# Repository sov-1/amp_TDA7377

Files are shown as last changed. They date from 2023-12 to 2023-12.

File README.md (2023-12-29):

 # Amplifier with audio-car amp TDA7377

This repo contains no only desing files for this amplifier but also an easy design for a coupling board that allows use the IC in any protoboard, this is under _proto_ folder wich has the gerber and .nc files for fabrication.

---
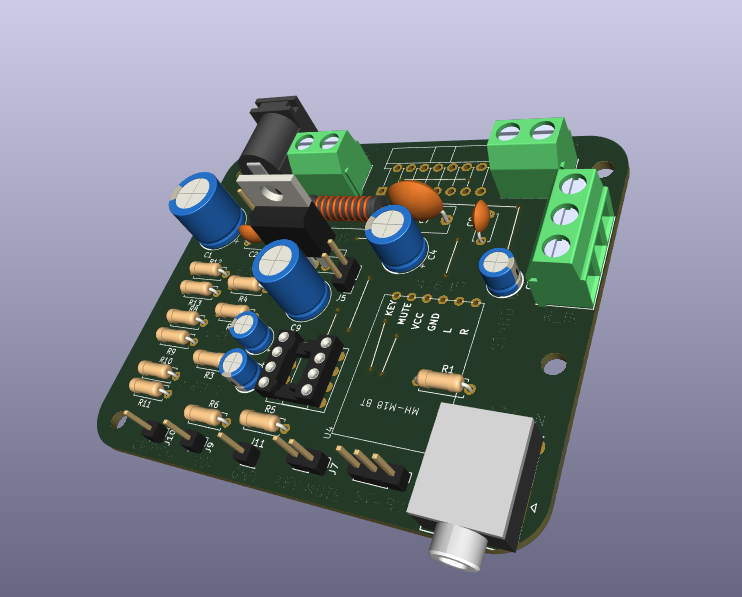
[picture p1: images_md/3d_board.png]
3D view


The goal it's to create a complete audio device 2.0 with audio jack - bluetooth input the cheapest way.
Following that, all is minded to be throug hole components, also using less space possible and carving circuits with a simple CNC 3018.

---
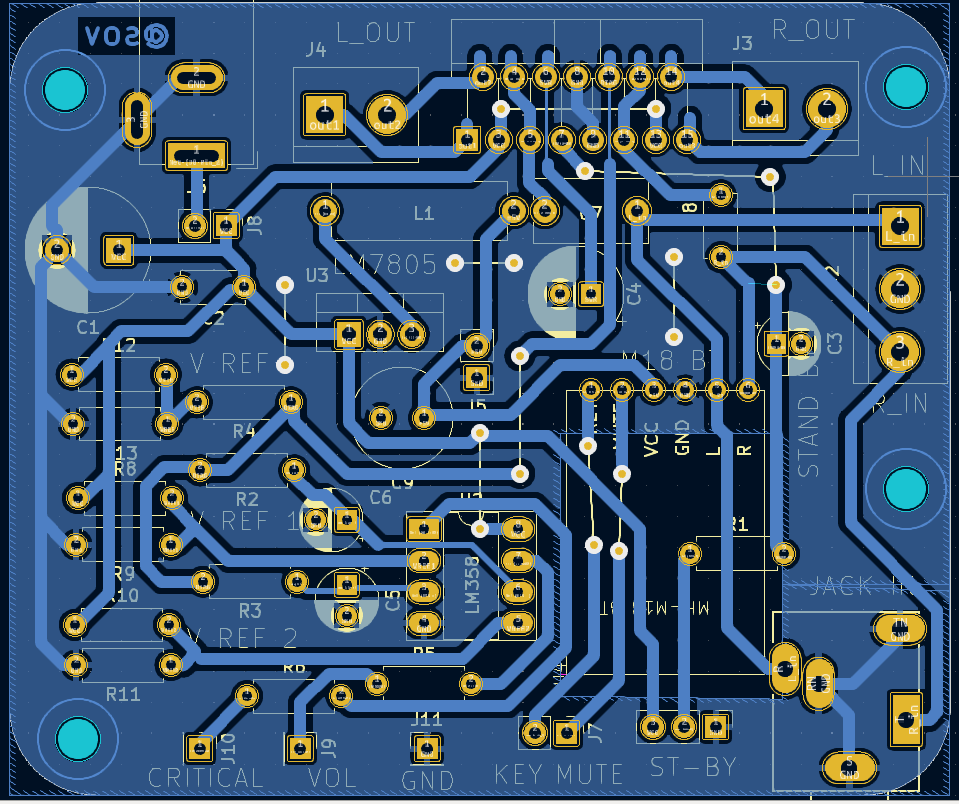
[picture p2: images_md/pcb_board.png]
pcb stage


At actual stage I got the basic functions (stereo input with audio Jack and bluetooth) but it's lacking the front board with leds and control, including switchs for power.

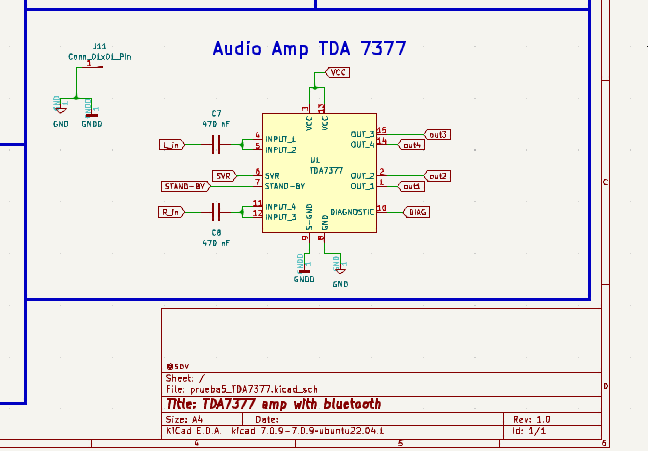
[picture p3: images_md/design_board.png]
circuit diagram


---

Some files in this project, like CAD models (.stp files) bornier and DC jack are not free and was obtained in web research.

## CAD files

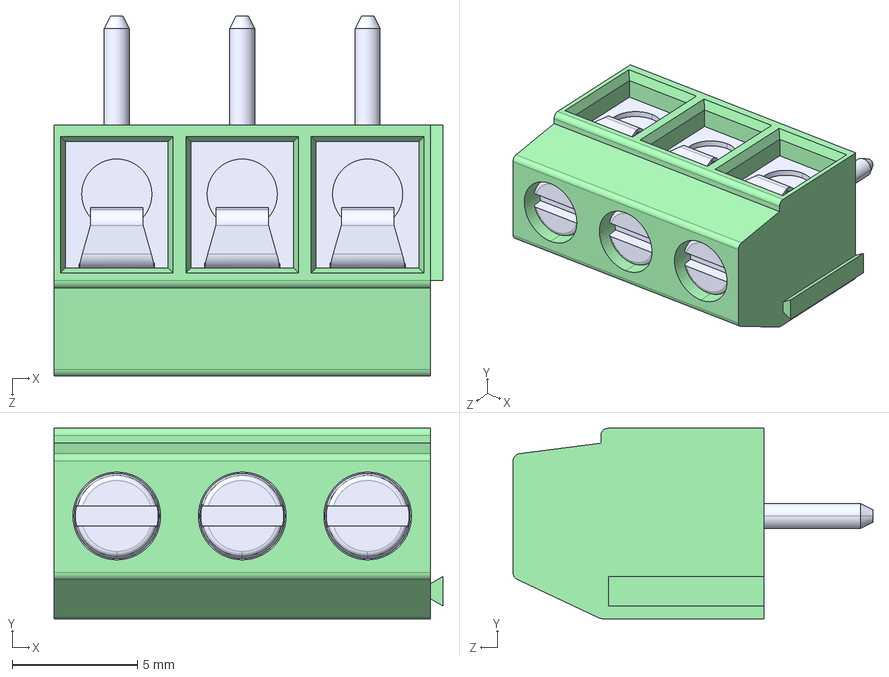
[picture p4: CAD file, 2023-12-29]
prueba5_TDA7377/terminalBlock_03.step
15.5 x 7.60 x 14.4 mm

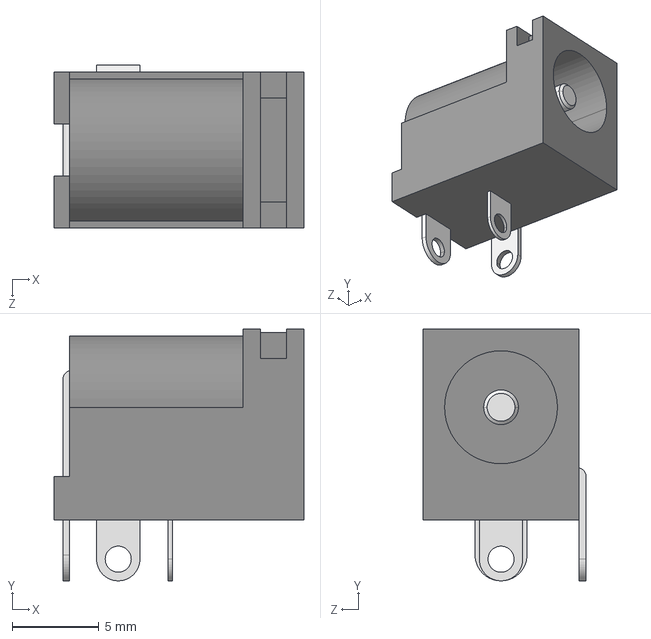
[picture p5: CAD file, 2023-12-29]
prueba5_TDA7377/JackDC_PJ-002AH.step
14.4 x 14.5 x 9.40 mm

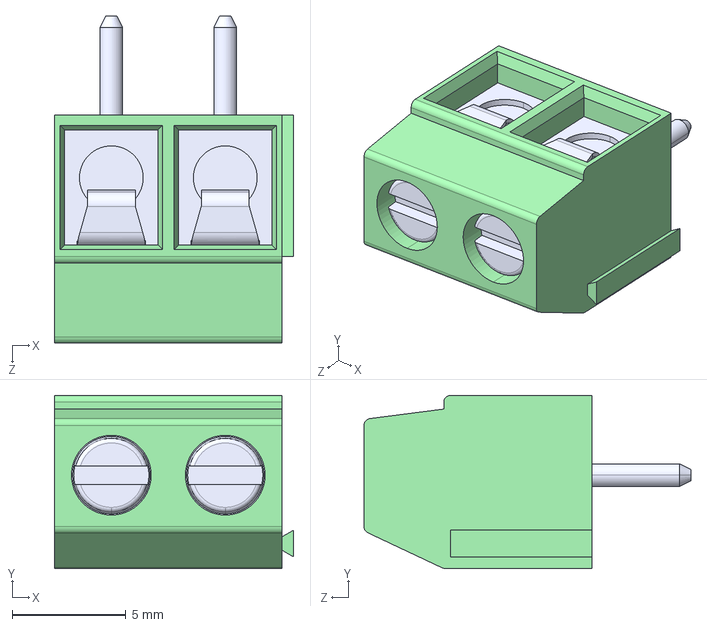
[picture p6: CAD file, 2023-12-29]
prueba5_TDA7377/terminalBlock_02.step
10.5 x 7.60 x 14.4 mm

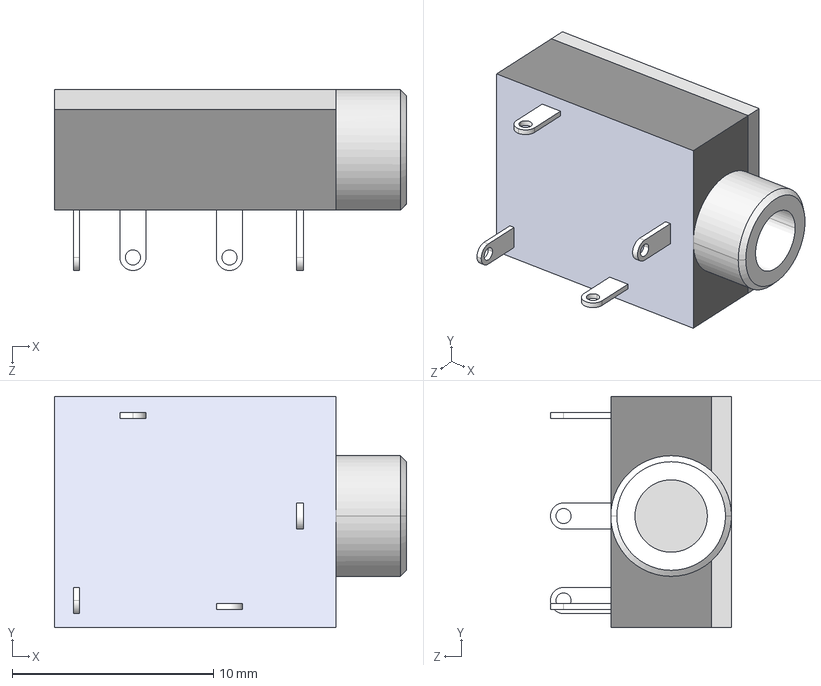
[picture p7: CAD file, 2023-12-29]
prueba5_TDA7377/AudioJack_SJ1-3514N.step
17.5 x 11.5 x 9.00 mm

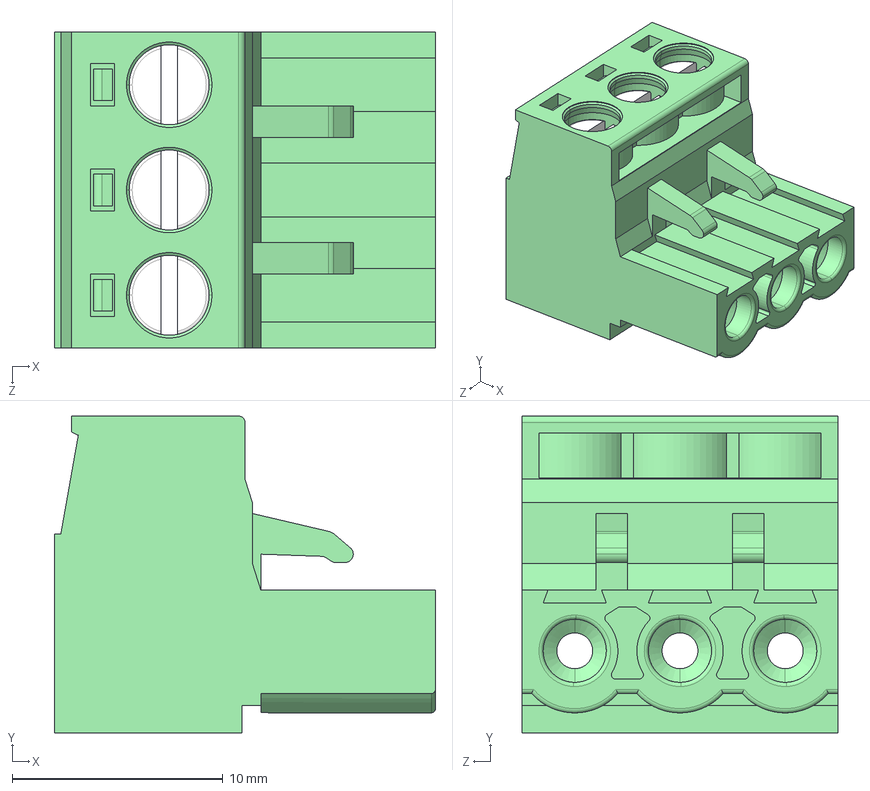
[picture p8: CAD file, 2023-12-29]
prueba5_TDA7377/terminalBlock_macho_03.step
18.1 x 15.1 x 15.0 mm

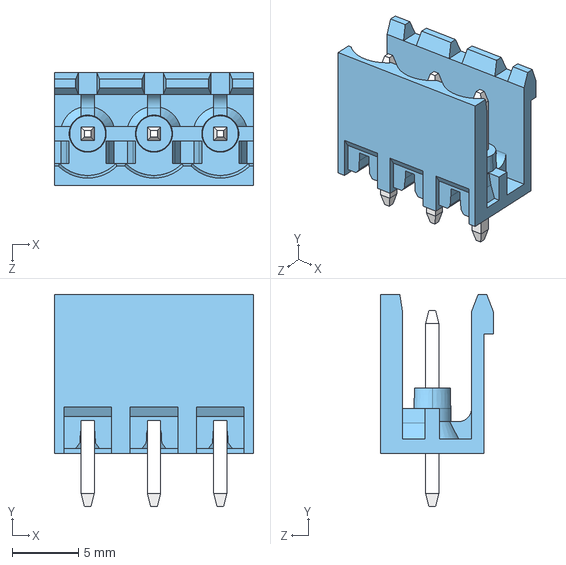
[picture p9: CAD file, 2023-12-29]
prueba5_TDA7377/terminalBlock_hembra_03.step
15.0 x 16.0 x 8.50 mm

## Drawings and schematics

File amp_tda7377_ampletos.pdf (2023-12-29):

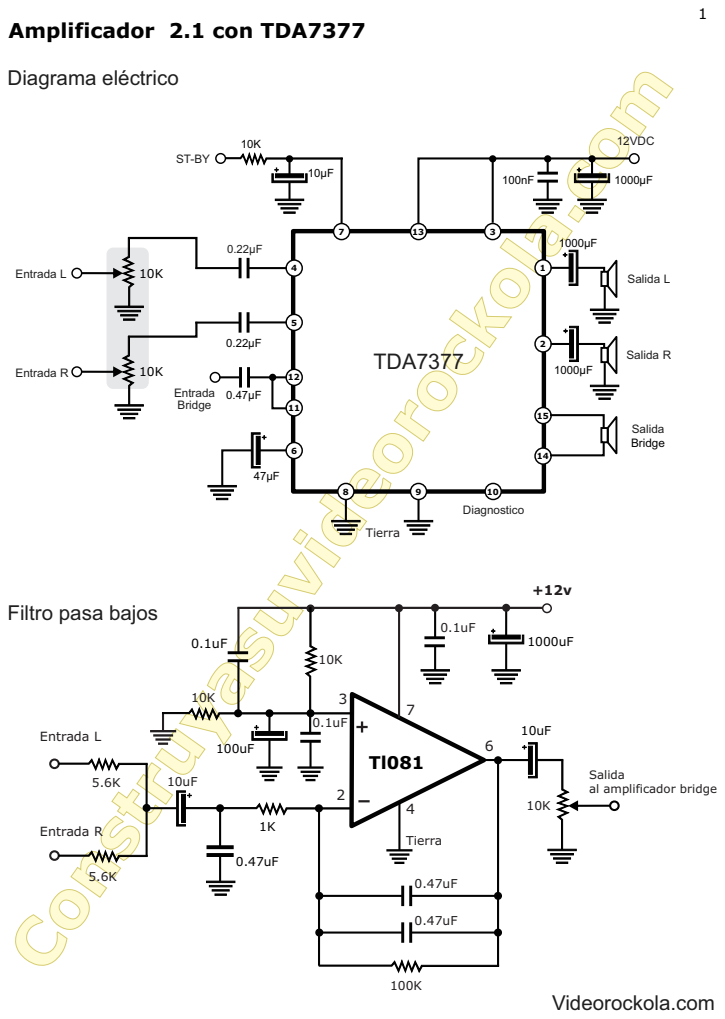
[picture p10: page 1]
Diagnostico; Entrada 0.47µF; 12VDC; Salida L; Salida Bridge; Salida R; TDA7377; Amplificador 2.1 con TDA7377; Diagrama eléctrico; Entrada L; Tierra; Entrada R; Bridge; Videorockola.com

Filtro pasa bajos

Salida
al amplificador bridge

## Preamplificador estéreo

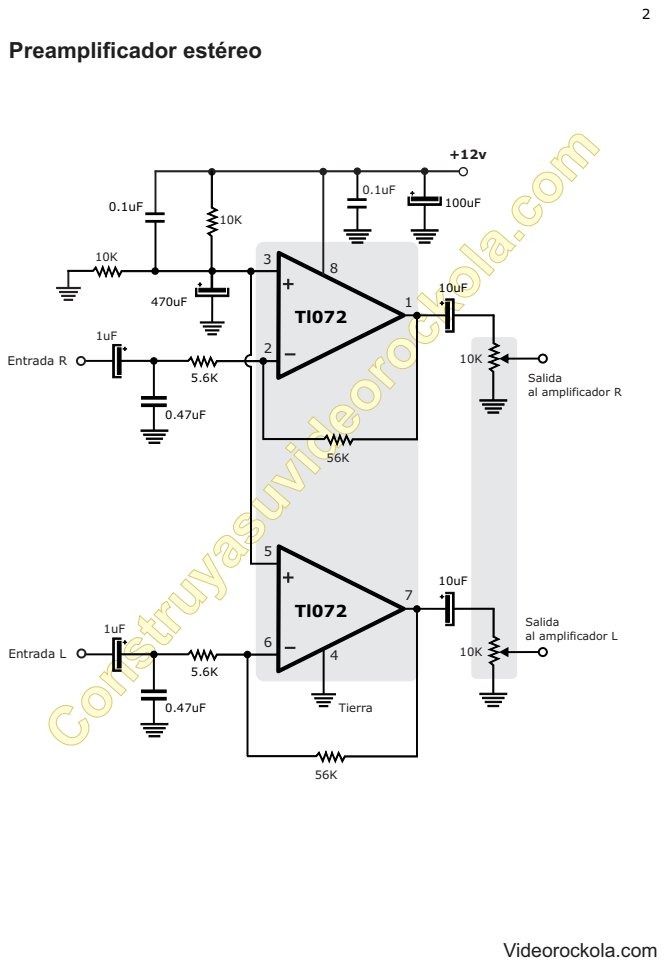
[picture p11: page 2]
Construyasuvideorockola.com; Salida al amplificador R; Entrada R; Salida al amplificador L 1uF; Tierra; Entrada L

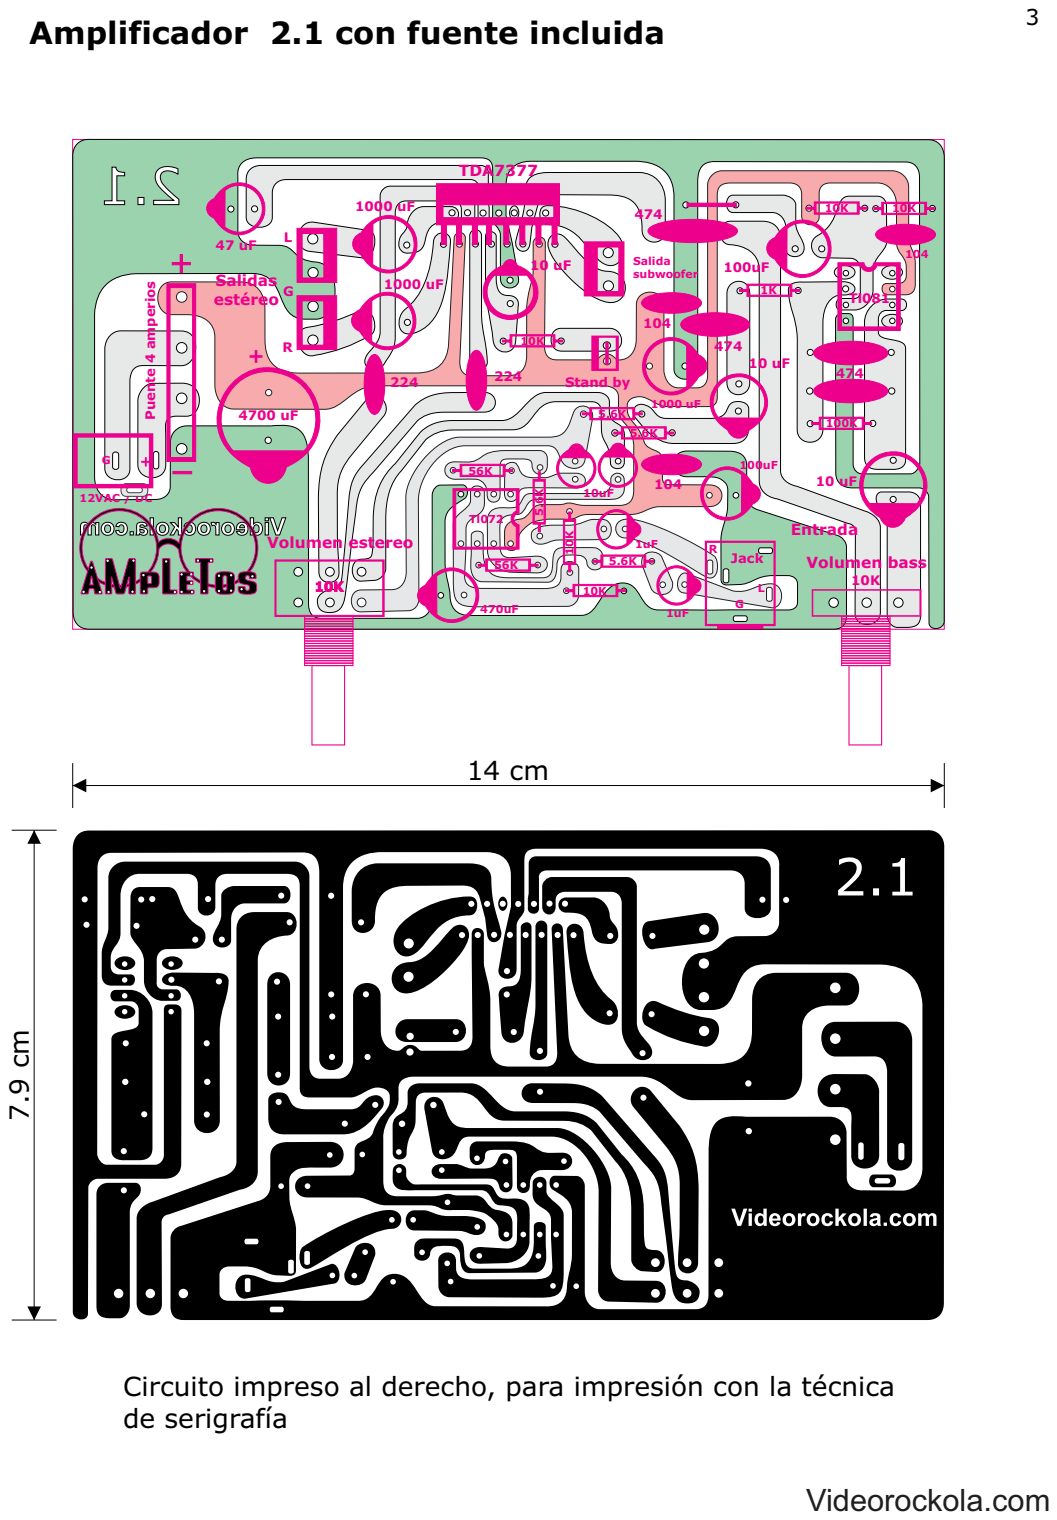
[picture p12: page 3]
5.6K ¹⁰K 5.6K; 12VAC / DC; Salida subwoofer; Stand by; Salidas estéreo; TDA7377; Volumen estereo; Volumen bass; Entrada; Jack; Puente 4 amperios

Amplificador 2.1 con fuente incluida

Circuito impreso al derecho, para impresión con la técnica
de serigrafía

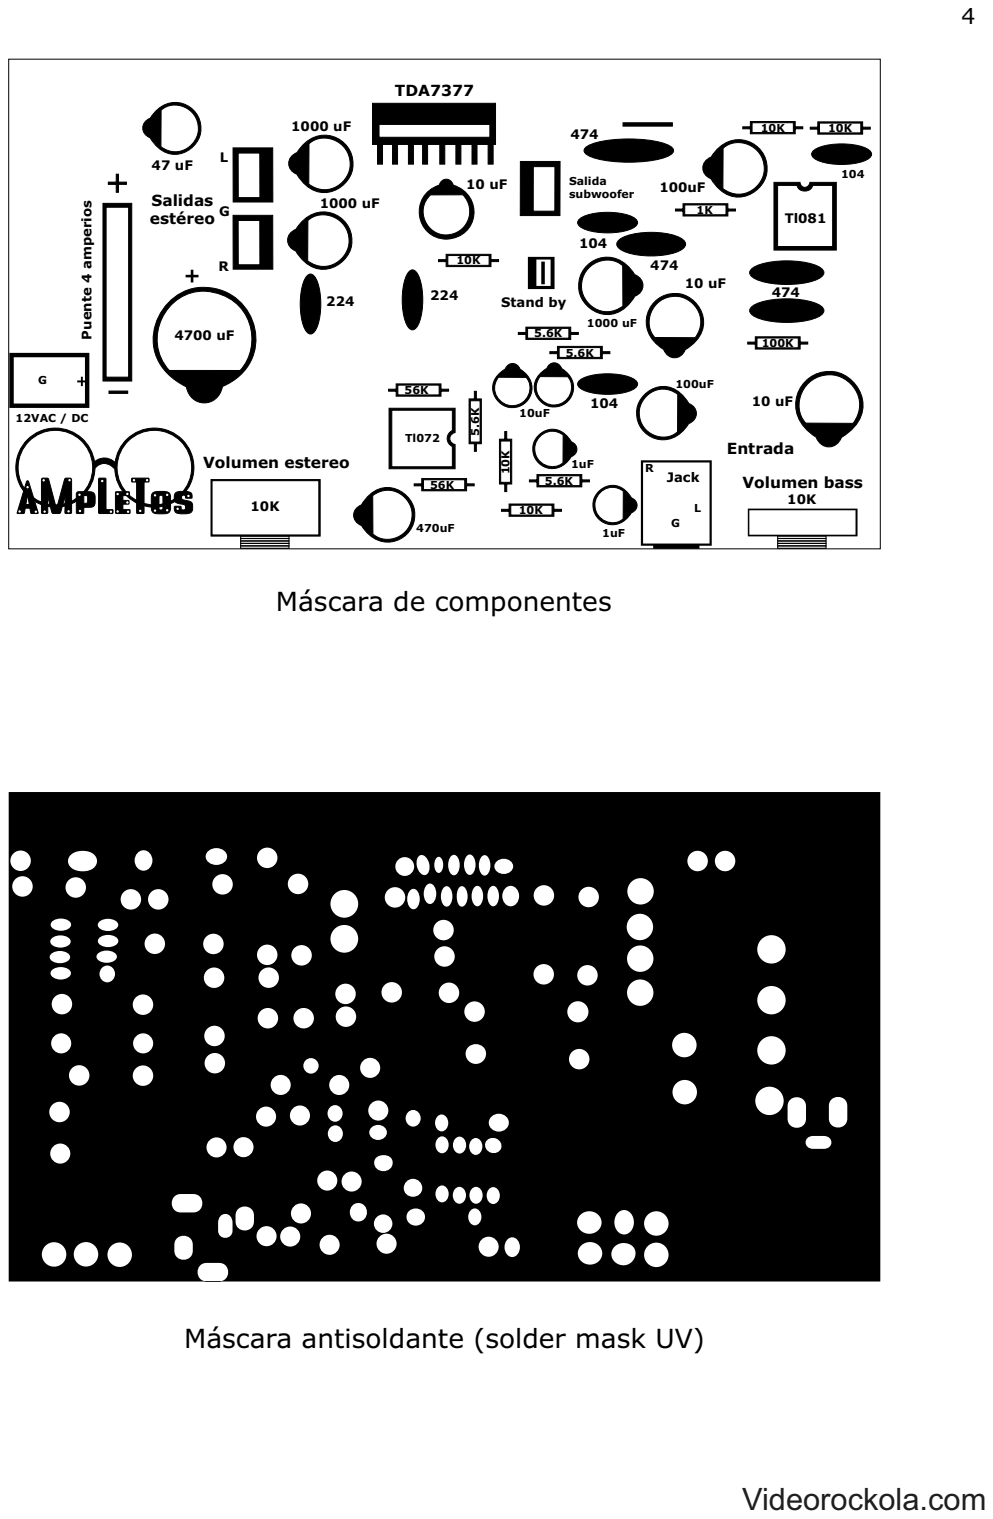
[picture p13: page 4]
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

Máscara de componentes

Máscara antisoldante (solder mask UV)

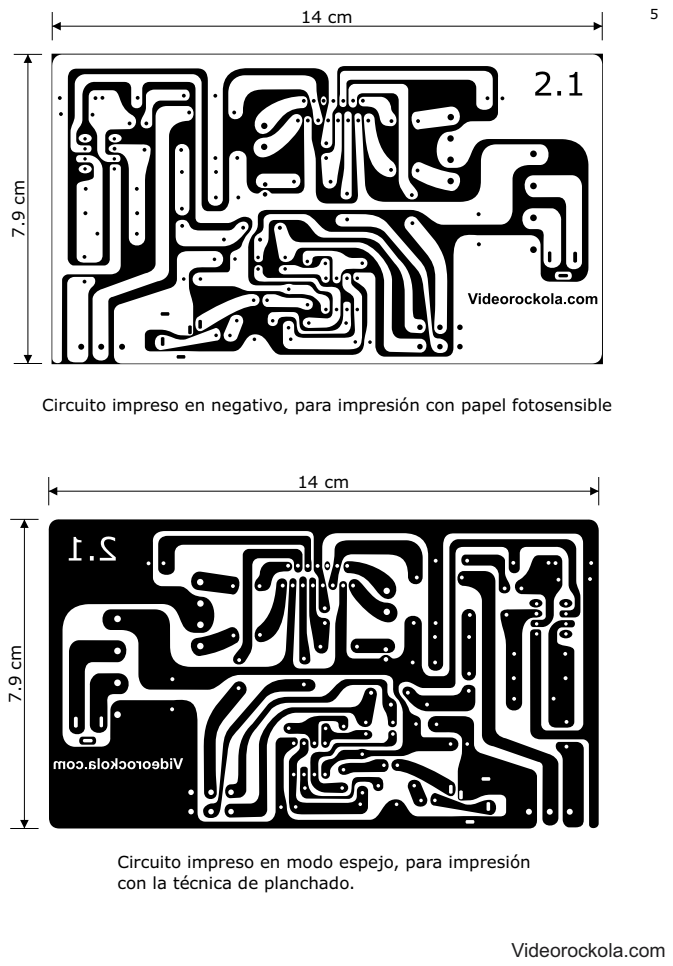
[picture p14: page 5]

Circuito impreso en negativo, para impresión con papel fotosensible

Circuito impreso en modo espejo, para impresión
con la técnica de planchado.

## Diagrama de conexión

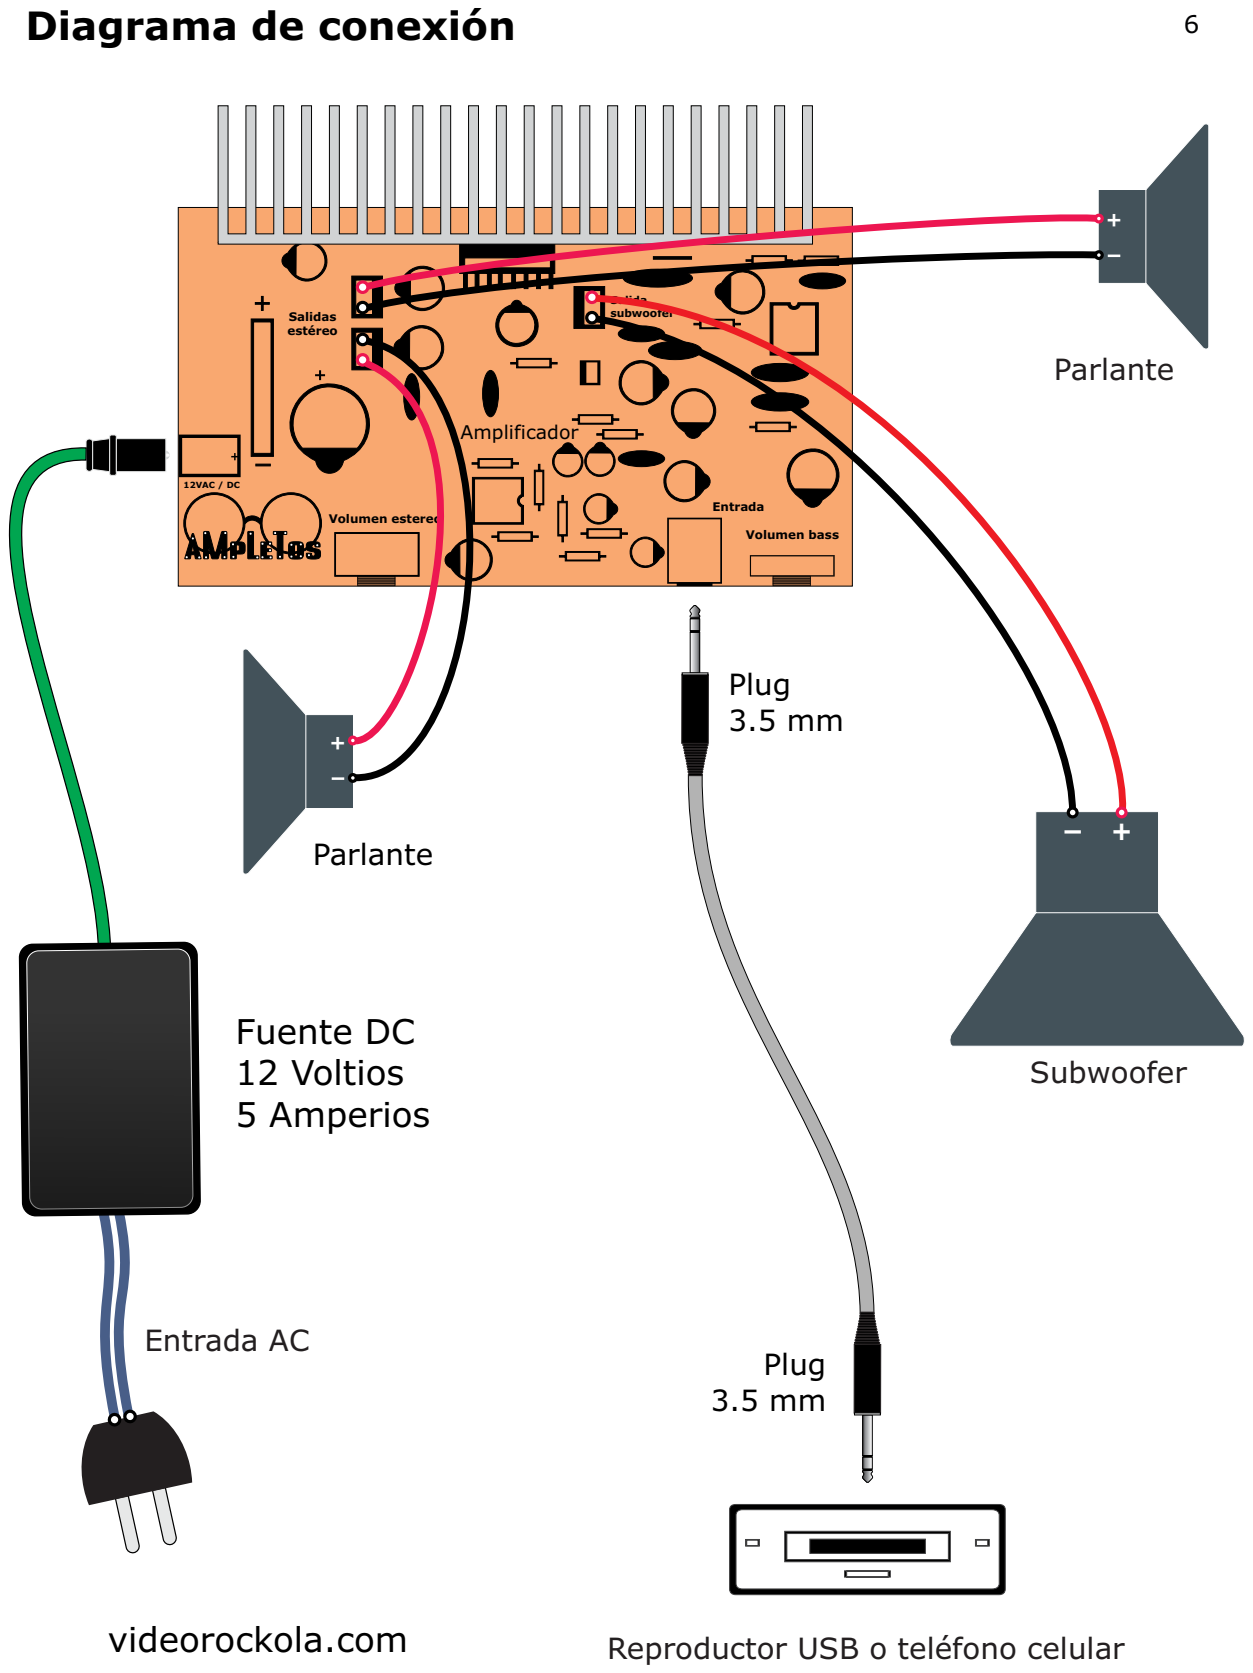
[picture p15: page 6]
12VAC / DC; Salida; Salidas; subwoofer; estéreo; Volumen estereo; Volumen bass; Entrada; Fuente DC 12 Voltios 5 Amperios; Entrada AC; Parlante; videorockola.com; Reproductor USB o teléfono celular; Amplificador; Plug 3.5 mm; Subwoofer

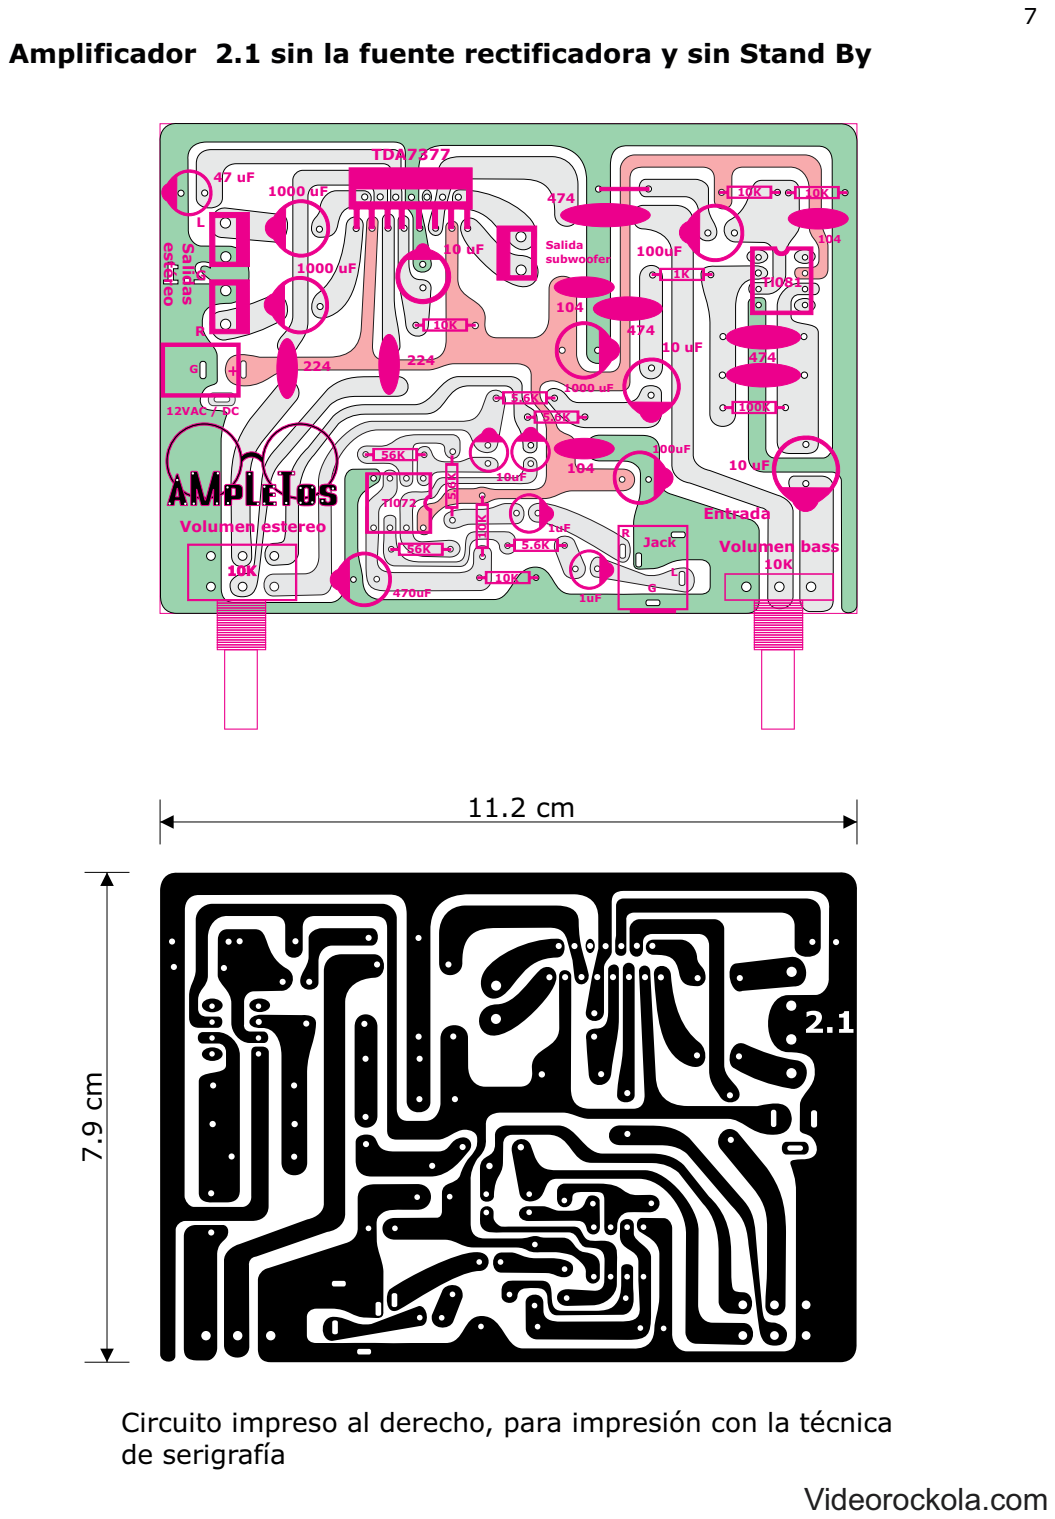
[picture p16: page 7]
5.6K ¹⁰K 5.6K; Salida subwoofer; estéreo; Salidas; TDA7377; Volumen estereo; Volumen bass; Entrada; Jack; 12VAC / DC

Amplificador 2.1 sin la fuente rectificadora y sin Stand By

Circuito impreso al derecho, para impresión con la técnica
de serigrafía

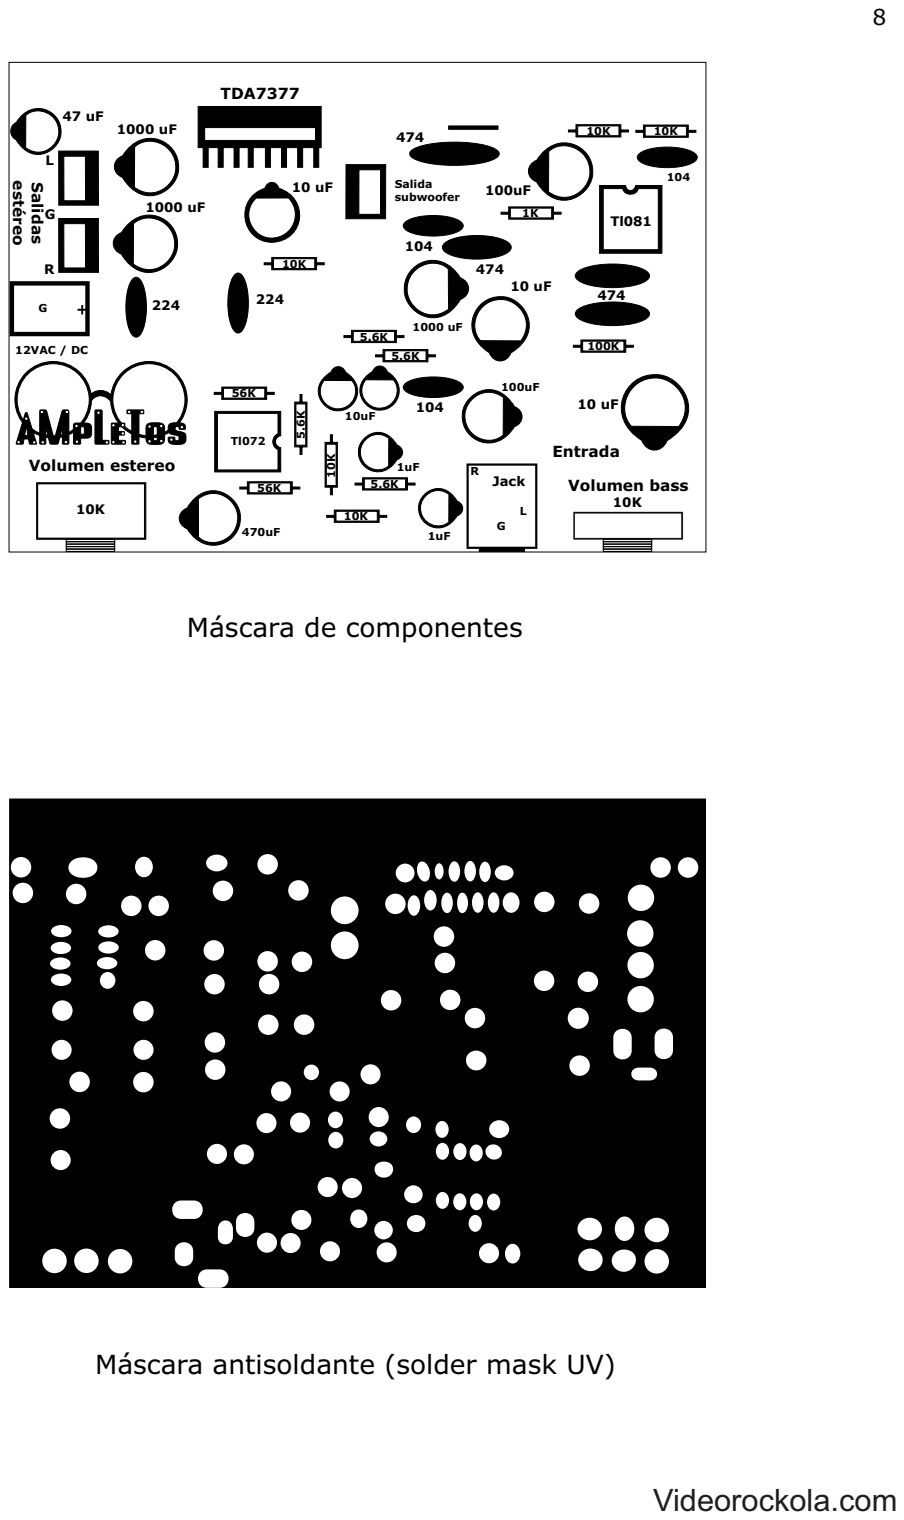
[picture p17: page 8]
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

Máscara de componentes

Máscara antisoldante (solder mask UV)

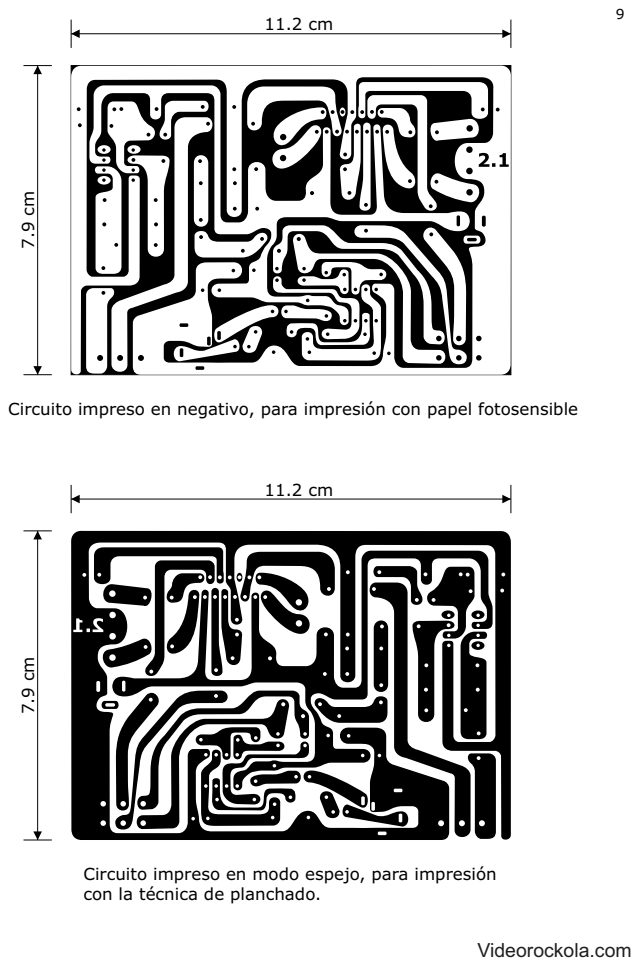
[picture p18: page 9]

Circuito impreso en negativo, para impresión con papel fotosensible

Circuito impreso en modo espejo, para impresión
con la técnica de planchado.

Lista de materiales

Circuitos integrados

1 TDA7377
1 Tl081
1 Tl072

Resistencias

2 Resistencias de 56K (verde, azul, naranja) 1 Resistencia de 100K (café, negro, amarillo) 5 Resistencias de 10K (café, negro, naranja) 1 Resistencia de 1K (café, negro, rojo)
4 Resistencias de 5.6K (verde, azul, rojo)

Condensadores

3 Condensadores de 1000uF a 16V en adelante 2 Condensadores de 100uF a 16V en adelante 5 Condensadores de 10uF a 16V en adelante 1 Condensador de 47uF a 16V en adelante
1 Condensador de 470uF a 16V en adelante 1 Condensador de 4.700uF a 16V en adelante 2 condensadores de 0.22uF (224) poliéster
4 condensadores de 0.47uF (474) poliéster
3 Condensadores de 0.1uF (104) poliéster
2 condensadores de 1uF a 16 voltios en adelante

Otros

1 potenciómetro doble de 10K
1 potenciómetro sencillo de 10K
1 conector de 2.54 mm de 2 pines (opcional)
3 conectores tipo bornera (Bloque) de 2 pines
Disipador de calor de 12 cm de largo x 5 cm de alto y 2 cm de grueso. 1 puente de diodos de 4 amperios en adelante (tipo peine)
Jack de 3.5 milímetros
Cable con plug estéreo de 3.5 milímetros en cada extremo.
Jack DC de 2.1 milímetros
2 bases para circuito integrado de 8 pines DIP
1 transformador de 12V AC y 5 amperios. (sólo en caso de hacer la versión con fuente incluida. También puede ser una fuente DC de 12VDC y 5 amperios, o una batería.

10

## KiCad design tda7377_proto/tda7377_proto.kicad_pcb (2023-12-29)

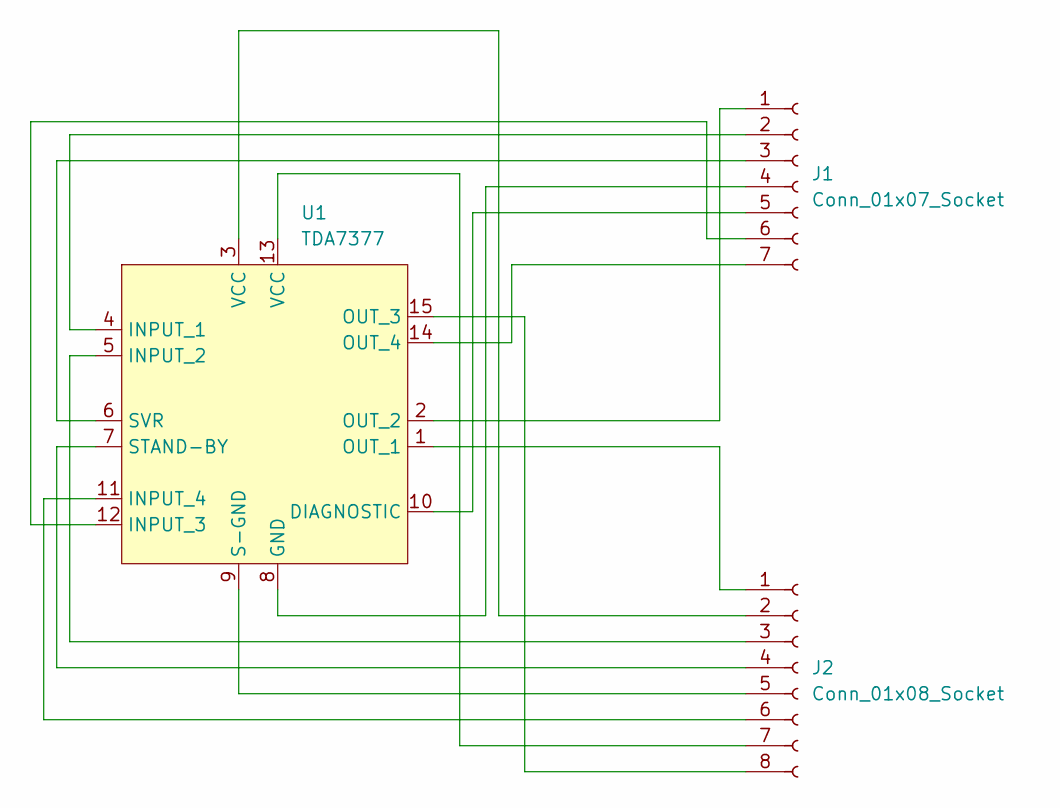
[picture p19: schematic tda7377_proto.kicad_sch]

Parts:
J1: Conn_01x07_Socket; PinHeader_1x07_P2.54mm_Vertical
J2: Conn_01x08_Socket; PinHeader_1x08_P2.54mm_Vertical
U1: TDA7377; TO-220-15_P2.54x2.54mm_StaggerOdd_Lead4.58mm_Vertical

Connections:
unnamed: J1.1, U1.2 (OUT_2)
unnamed: J1.2, U1.4 (INPUT_1)
unnamed: J1.3, U1.6 (SVR)
unnamed: J1.4, U1.8 (GND)
unnamed: J1.5, U1.10 (DIAGNOSTIC)
unnamed: J1.6, U1.12 (INPUT_3)
unnamed: J1.7, U1.14 (OUT_4)
unnamed: J2.1, U1.1 (OUT_1)
unnamed: J2.2, U1.3 (VCC)
unnamed: J2.3, U1.5 (INPUT_2)
unnamed: J2.4, U1.7 (STAND-BY)
unnamed: J2.5, U1.9 (S-GND)
unnamed: J2.6, U1.11 (INPUT_4)
unnamed: J2.7, U1.13 (VCC)
unnamed: J2.8, U1.15 (OUT_3)

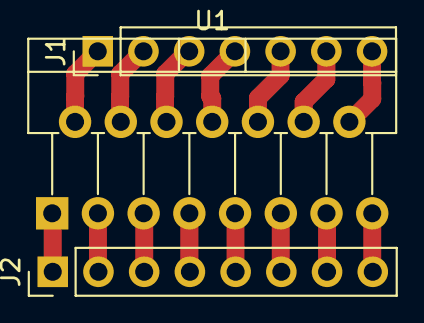
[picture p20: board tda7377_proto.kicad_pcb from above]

Board: 2 copper layers, 3 parts (0 on the bottom side), 15 nets.

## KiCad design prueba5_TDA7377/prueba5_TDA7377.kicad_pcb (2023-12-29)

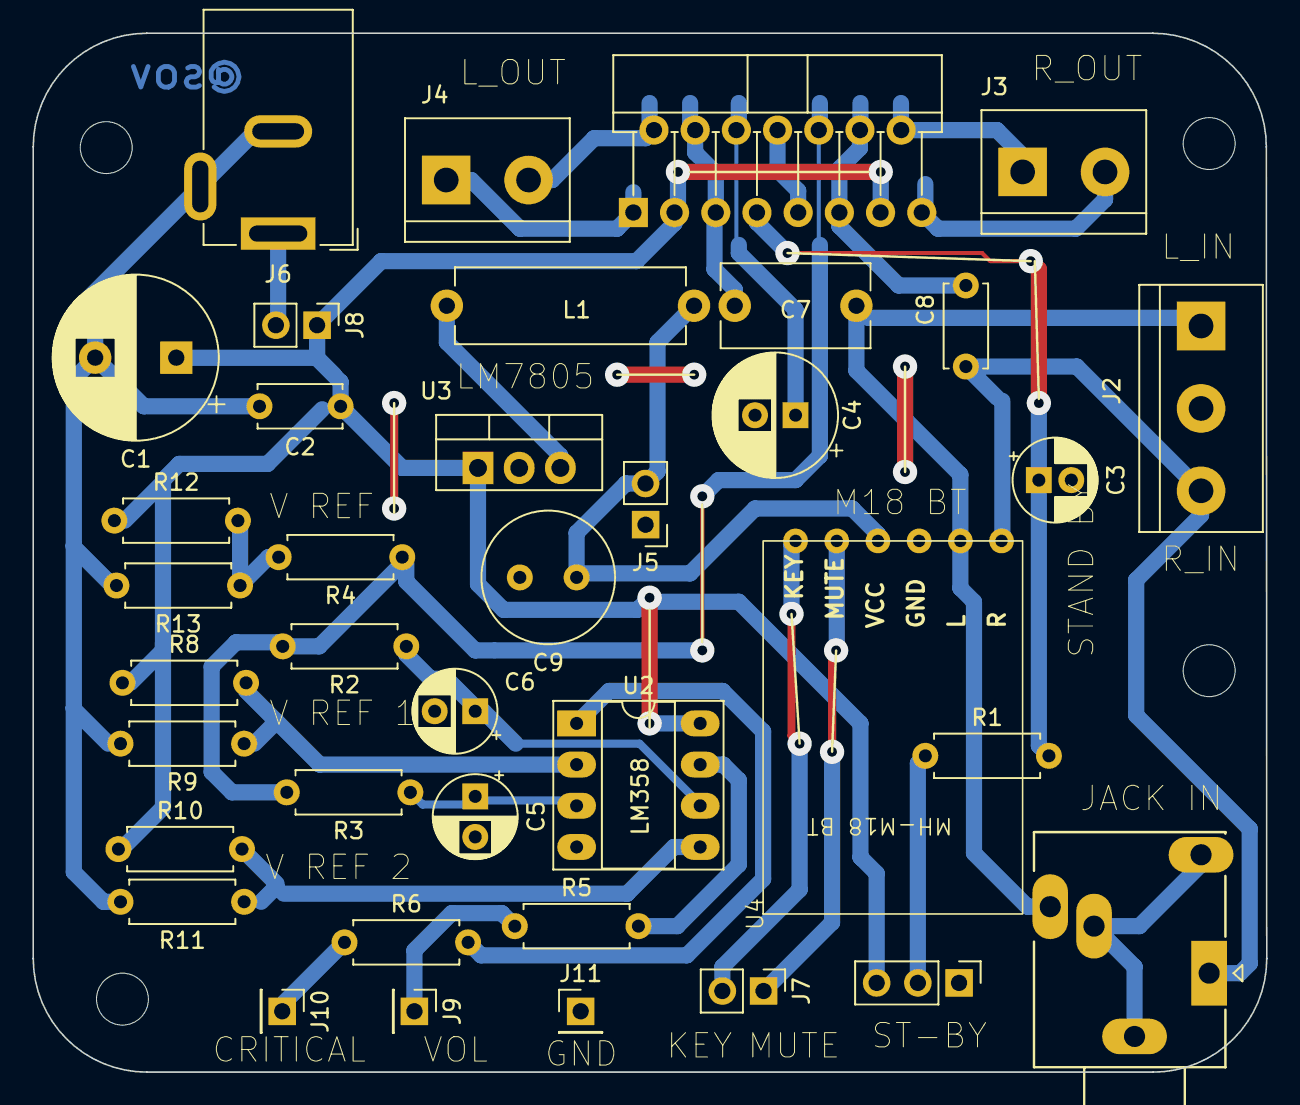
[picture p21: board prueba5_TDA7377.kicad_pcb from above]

Board: 2 copper layers, 76.1 x 64.1 mm, 38 parts (0 on the bottom side), 28 nets.

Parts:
C1: 470 uF; CP_Radial_D10.0mm_P5.00mm
C2: 100 nF; C_Disc_D5.0mm_W2.5mm_P5.00mm
C3: 10 uF; CP_Radial_D5.0mm_P2.00mm
C4: 47 uF; CP_Radial_D7.5mm_P2.50mm
C5, C6: 10 uF; CP_Radial_D5.0mm_P2.50mm
C7: 470 nF; C_Disc_D9.0mm_W5.0mm_P7.50mm
C8: 470 nF; C_Disc_D5.0mm_W2.5mm_P5.00mm
C9: 200 uF; C_Radial_D8.0mm_H11.5mm_P3.50mm
J1: AudioJack3_Switch; Jack_3.5mm_Ledino_KB3SPRS_Horizontal
J2: Screw_T; TerminalBlock_bornier-3_P5.08mm
J3, J4: Screw_T; TerminalBlock_bornier-2_P5.08mm
J5, J7, J8: Conn_01x02_Pin; PinHeader_1x02_P2.54mm_Vertical
J6: Jack-DC; BarrelJack_GCT_DCJ200-10-A_Horizontal
J9, J10, J11: Conn_01x01_Pin; PinHeader_1x01_P2.54mm_Vertical
L1: 100 mH; L_Axial_L14.0mm_D4.5mm_P15.24mm_Horizontal_Fastron_LACC
R1: 10 k; R_Axial_DIN0207_L6.3mm_D2.5mm_P7.62mm_Horizontal
R2, R4, R10: 10k; R_Axial_DIN0207_L6.3mm_D2.5mm_P7.62mm_Horizontal
R3: 100k; R_Axial_DIN0207_L6.3mm_D2.5mm_P7.62mm_Horizontal
R5, R6: 1.2k; R_Axial_DIN0207_L6.3mm_D2.5mm_P7.62mm_Horizontal
R8: 500; R_Axial_DIN0207_L6.3mm_D2.5mm_P7.62mm_Horizontal
R9, R11, R13: 1k; R_Axial_DIN0207_L6.3mm_D2.5mm_P7.62mm_Horizontal
R12: 200; R_Axial_DIN0207_L6.3mm_D2.5mm_P7.62mm_Horizontal
ST-BY: button; PinHeader_1x03_P2.54mm_Vertical
U1: TDA7377; TO-220F-15_P2.54x5.08mm_StaggerOdd_Lead5.08mm_Vertical
U2: LM358; DIP-8_W7.62mm_Socket_LongPads
U3: LM78M05_TO220; TO-220-3_Vertical
U4: MH M18; M18

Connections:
+5V: C9.1, J5.2, L1.2, U4.3 (VCC)
DIAG: R2.2, R3.2, R4.1, U1.10 (DIAGNOSTIC)
GND: C1.2, C2.2, C3.2, C4.2, C5.2, C6.2, C9.2, J1.RN, J1.S, J1.TN, J2.2, J5.1, J6.2, J6.3, J11.1, R9.2, R11.2, R13.2, ST-BY.1 (A), U1.8 (GND), U1.9 (S-GND), U2.4 (V-), U3.2 (GND), U4.4 (GND)
LED_CRITICAL: J10.1, R6.1
LED_VOLUME: J9.1, R5.1
L_in: C7.1, J1.R, J2.1, U4.5 (L)
unnamed: J7.1, U4.2 (MUTE)
unnamed: J7.2, U4.1 (KEY)
unnamed: J6.1, J8.2
unnamed: R5.2, U2.7
unnamed: R6.2, U2.1
unnamed: R1.1, ST-BY.2 (B)
unnamed: C7.2, U1.4 (INPUT_1), U1.5 (INPUT_2)
unnamed: C8.1, U1.11 (INPUT_4), U1.12 (INPUT_3)
unnamed: C5.1, R3.1, U2.3 (+)
unnamed: C6.1, R2.1, U2.6 (-)
unnamed: L1.1, U3.3 (VO)
R_in: C8.2, J1.T, J2.3
STAND-BY: C3.1, R1.2, U1.7 (STAND-BY), U4.6 (R)
SVR: C4.1, U1.6 (SVR)
VCC: C1.1, C2.1, J8.1, R8.1, R10.1, R12.1, ST-BY.3 (C), U1.3 (VCC), U1.13 (VCC), U2.8 (V+), U3.1 (VI)
VREF: R4.2, R12.2, R13.1
VREF1: R8.2, R9.1, U2.2 (-)
VREF2: R10.2, R11.1, U2.5 (+)
out1: J4.1, U1.1 (OUT_1)
out2: J4.2, U1.2 (OUT_2)
out3: J3.2, U1.15 (OUT_3)
out4: J3.1, U1.14 (OUT_4)
